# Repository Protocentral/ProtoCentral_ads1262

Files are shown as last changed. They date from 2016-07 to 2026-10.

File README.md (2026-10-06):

ADS1262 Breakout Board
=======================

ADS1262 32-bit, 11-Channel Multifunction Low-Noise, High-Resolution ADC Breakout Board (PC-4143)

[Don't have it yet? Buy one here: ProtoCentral ADS1262 32-bit precision ADC breakout board (PC-4143)](https://protocentral.com/product/protocentral-ads1262-32-bit-precision-adc-breakout-board/)
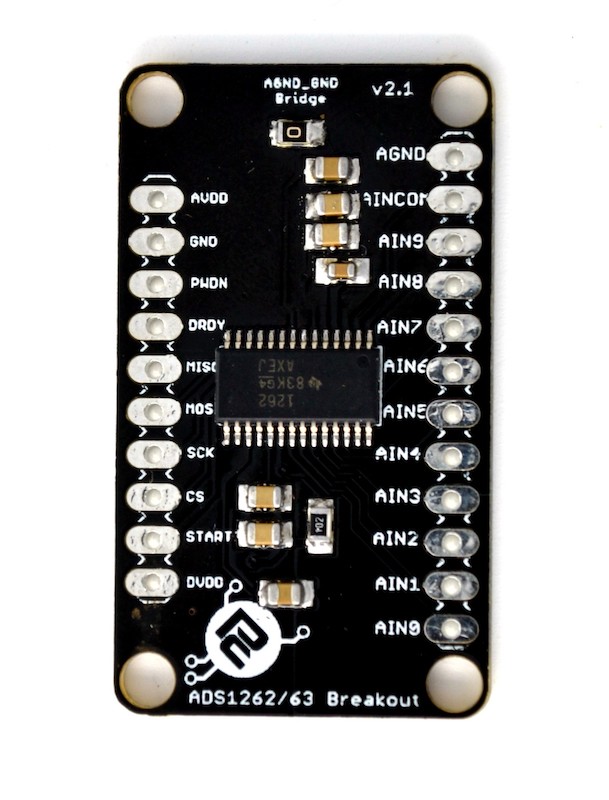
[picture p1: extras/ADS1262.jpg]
ADC breakout


The 24-bit ADS1220 ADC still not enough for you? Need more? Look no further than the ADS1262 from Texas Instruments — a 32-bit Delta-Sigma ADC with a built-in PGA, voltage reference, current sources and everything else but the kitchen sink.

What does 32-bit precision mean to you? Compared to a commonly used 12-bit ADC which can provide 4,096 levels of the input analog voltage, a 32-bit ADC can, in theory, provide 4,294,967,296 levels!

Now plug-in your high-precision strain gauge or load cell directly to this ADC without any external analog signal conditioning. Whether it is for ultra-high precision weighing scales, strain gauges, RTDs or chemical sensors, you can be assured that you will get the highest available precision from this breakout board.

Features
---------
* Ultra-high precision 32-bit Delta-Sigma ADC
* 11 programmable analog inputs (AIN0-AIN9 + AINCOM)
* Differential Input Programmable Gain Amplifier (PGA): 1x to 32x
* Programmable Data Rates: 2.5 SPS to 38.4 kSPS
* 2 built-in current sources for sensor excitation
* Built-in programmable digital filter
* Internal Voltage Reference (2.5 V)
* Internal temperature sensor
* SPI interface
* 3.3V or 5V operation

Specifications
---------------

### Input Ranges (with 2.5V internal reference)

| Gain | Input Range  | Optimal Use Case |
|:----:|:---:|---|
| 1x | +/-2.5V | High voltage signals |
| 2x | +/-1.25V | Medium voltage signals |
| 4x | +/-625mV | Low voltage signals |
| 8x | +/-312.5mV | Very low voltage signals |
| 16x  | +/-156.25mV  | Strain gauges |
| 32x  | +/-78.125mV  | Ultra-low signals, load cells |

Applications
-------------
* High precision analog voltage measurement
* Strain gauges and load cells
* RTD (Resistance Temperature Detector) interfacing
* Thermocouple measurement
* High precision chemical sensors (pH, conductivity)
* Multi-channel data acquisition systems
* Calibration and reference equipment

Wiring to your Arduino
-----------------------
| ADS1262 Pin | Pin Function | Arduino Connection |
|---|:---:|---:|
| DRDY | Data Ready Output | D6 |
| MISO | Slave Out (SPI) | D12 |
| MOSI | Slave In (SPI) | D11 |
| SCLK | Serial Clock (SPI) | D13 |
| CS | Chip Select | D7 |
| START | Start Conversion | D5 |
| PWDN | Power Down / Reset | D4 |
| DVDD | Digital VDD | +5V |
| DGND | Digital Gnd | GND |
| AN0-AN9 | Analog Inputs | Analog Input |
| AINCOM | Analog Input Common  | |
| AVDD | Analog VDD | +5V |
| AGND | Analog Gnd | GND |

Getting Started
----------------

Install the library through the Arduino Library Manager (search for "ProtoCentral ADS1262") or clone this repository into your Arduino libraries folder.

```cpp
#include <ads1262.h>

ADS1262 adc;

void setup() {
    Serial.begin(115200);

    if (!adc.begin()) {
        Serial.println("Failed to initialize ADS1262!");
        while(1);
    }

    // Configure for your application
    adc.setDataRate(ADS1262_DR_100_SPS);
    adc.setGain(ADS1262_GAIN_1);
    adc.setInputMux(ADS1262_AIN0, ADS1262_AIN1);
}

void loop() {
    float voltage = adc.readVoltage();
    Serial.print("Voltage: ");
    Serial.print(voltage, 6);
    Serial.println(" V");
    delay(1000);
}
```

The example sketches are configured for internal Vref = 2.50V and differential voltage measurement across AIN0 and AIN1.

Repository Contents
-------------------
* **/src** - Arduino library source files
* **/examples** - Example Arduino sketches
* **/Hardware** - Eagle design files (.brd, .sch) for the original board
* **/Hardware/v4** - KiCad design files and schematic PDF for the v4 board (single 3.3 V / 5 V supply pin, on-board LM2775 charge pump)
* **/extras** - Includes the datasheet

License Information
===================

License

This product is open source! Both, our hardware and software are open source and licensed under the following licenses:

Hardware
---------

**All hardware is released under the [CERN-OHL-P v2](https://ohwr.org/cern_ohl_p_v2.txt)** license.

Copyright CERN 2020.

This source describes Open Hardware and is licensed under the CERN-OHL-P v2.

You may redistribute and modify this documentation and make products
using it under the terms of the CERN-OHL-P v2 (https:/cern.ch/cern-ohl).
This documentation is distributed WITHOUT ANY EXPRESS OR IMPLIED
WARRANTY, INCLUDING OF MERCHANTABILITY, SATISFACTORY QUALITY
AND FITNESS FOR A PARTICULAR PURPOSE. Please see the CERN-OHL-P v2
for applicable conditions

Software
--------

**All software is released under the MIT License(http://opensource.org/licenses/MIT).**

THE SOFTWARE IS PROVIDED "AS IS", WITHOUT WARRANTY OF ANY KIND, EXPRESS OR IMPLIED, INCLUDING BUT NOT LIMITED TO THE WARRANTIES OF MERCHANTABILITY, FITNESS FOR A PARTICULAR PURPOSE AND NONINFRINGEMENT. IN NO EVENT SHALL THE AUTHORS OR COPYRIGHT HOLDERS BE LIABLE FOR ANY CLAIM, DAMAGES OR OTHER LIABILITY, WHETHER IN AN ACTION OF CONTRACT, TORT OR OTHERWISE, ARISING FROM, OUT OF OR IN CONNECTION WITH THE SOFTWARE OR THE USE OR OTHER DEALINGS IN THE SOFTWARE.

Documentation
-------------
**All documentation is released under [Creative Commons Share-alike 4.0 International](http://creativecommons.org/licenses/by-sa/4.0/).**


You are free to:

* Share — copy and redistribute the material in any medium or format
* Adapt — remix, transform, and build upon the material for any purpose, even commercially.
The licensor cannot revoke these freedoms as long as you follow the license terms.

Under the following terms:

* Attribution — You must give appropriate credit, provide a link to the license, and indicate if changes were made. You may do so in any reasonable manner, but not in any way that suggests the licensor endorses you or your use.
* ShareAlike — If you remix, transform, or build upon the material, you must distribute your contributions under the same license as the original.

Please check [*LICENSE.md*](LICENSE.md) for detailed license descriptions.

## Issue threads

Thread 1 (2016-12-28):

Specified folder/zip file does not contain a valid library

ecaits, 2016-12-28:
I have installed this library but when I compile the example code I got the error of Specified folder/zip file does not contain a valid library.

What can be the issue???

VenkateshBhat, 2016-12-28:
Please unzip the files, and place the src file in appropriate folder ,in the Arduino IDE, navigate to Sketch > Include Library.

ecaits, 2016-12-28:
Already unzip the files but no src file is found. Can you please suggest for that?
Send me the link for that.

ecaits, 2016-12-28:
Now its working... There was a spelling mistake in example.ino file....
I have used MISO, MOSI, CS, SCK, Start and DRDY pin... I have not used PWDN pin as I have limited pins on boards....
Thanks for your support...

aravindaguru, 2018-02-16:
I have installed this library but when I compile the example code I got the error of Specified folder/zip file does not contain a valid library.i have unzip the files but no src file is found. Can you please suggest for that?

aravindaguru, 2018-02-16:
i am getting this error
 C:\Users\manoj12126\AppData\Local\Temp\Temp1_ProtoCentral_ads1262-master.zip\ProtoCentral_ads1262-master\Libraries\example\example.ino:24:28: fatal error: SoftwareSerial.h: No such file or directory  #include <SoftwareSerial.h>

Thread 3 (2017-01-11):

ADS1262 and 2.2 SPI TFT (Two SPI Slave) with Arduino

ecaits, 2017-01-11:
Hello,

I am interfacing two SPI slave module i.e. ADS1262 and 2.2 SPI TFT with Arduino Ethernet board.
Now in SPI, at a time one device can access. Initially, I have interfaced TFT and it is working fine.
Then I have interface ADS1262 and trying to access after TFT through program code but it is not accessible.
Whereas the example code of ADS1262 is working fine when I am running it alone.
After adding the example code in TFT’s code (and communicating after tft) but it is not working.

I think it may the issue of ADS1262_CS or ADS1262_START or ADS1262_DRDY pin sequence to access the ADS1262.
I have used this library, https://github.com/Protocentral/ProtoCentral_ads1262/tree/master/Libraries and example of it.

Can you suggest for above issue.

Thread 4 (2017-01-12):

Single-Ended mode

Sumsa, 2017-01-12:
Hi There,

Do you have any idea how to make this work in Single-Ended mode? i.e measure the voltage difference between input A0 and COM. The documentations says the 1262 should be able to operate in this mode, but I cant figure out how to switch when looking at the example.

Along the same lines, where do I make changes if i want to measure from different pins than AN0 And AN1?

ecaits, 2017-01-13:
You need use INPMUX register to set the different analog pin as input.

Sumsa, 2017-01-17:
Thank you for pointing me in the right direction. Here is a small guide for people having the same problem.

for single mode operation connect the negative differential pin to ground using a jumper wire.

Change the pins used in line 78 in ads1262.cpp

e.g change the hex value next to INPMUX to a binary number as stated on page 94 in the datasheet. eg
ads1262_Reg_Write(INPMUX, B00000001); // will be AIN pin 0 and 1
ads1262_Reg_Write(INPMUX, B01110010); // will be AIN pin 7 and 2

To change the sampling rate to 10Hz where there is the highest db 50/60Hz noise reduction change mode 2 at line 62 to:
ads1262_Reg_Write(MODE2, B00000010);

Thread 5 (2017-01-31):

ADS1262 activation issue

ecaits, 2017-01-31:
I am interfacing ADS1262 with Arduino mega2560 along with TFT, sd card and AD420.
The example given in library of ads1262 is working perfectly but when I interface ads1262 with other slave at that time, sometimes it activate and given output and sometimes it does not activate so not getting serial output.

Is there voltage related problem or anything else?

VenkateshBhat, 2017-02-01:
Hi ecaits,

Sorry for the inconvenience caused, could you please share your design? What other slave you are interfacing with?

ecaits, 2017-02-06:
I am interfacing TFT 2.2 SPI and SD Card along with ProtoCentral_ads1262 ADS1262.
When I run the code, the ADS1262 gives wrong value. Although it is giving perfect value when running independently.
What may be the issue. I have attached photo of interfacing design.
[Circuit.pdf](https://github.com/Protocentral/ProtoCentral_ads1262/files/754511/Circuit.pdf)

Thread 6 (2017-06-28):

PDF of v3 Schematics / Layout

josschne, 2017-06-28:
Could we get a PDF of the v3 hardware schematics and layout for those without Eagle?

I see the v3 design files but no PDF.
https://github.com/Protocentral/ADS1292rShield_Breakout/tree/master/Hardware/ECG_BOB

VenkateshBhat, 2017-06-29:
Thank you for bringing this to our attention, now we have added the pdf file for the breakout https://github.com/Protocentral/ADS1292rShield_Breakout/tree/master/Hardware/ECG_BOB

josschne, 2017-06-29:
Thanks for the fast response. However, the PDF is missing the second sheet.

Could I see the second sheet too? The v3 hardware has logic level selection circuitry that I'd like to examine.

VenkateshBhat, 2017-06-30:
added, do check.

josschne, 2017-06-30:
Thanks!

Closed 2017-06-29.

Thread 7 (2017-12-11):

VDD

eduhza, 2017-12-11:
Hi,

I want to sugest that next version of "PROTOCENTRAL ADS1262 32-BIT PRECISION ADC BREAKOUT BOARD" have an option to use as VDD +5V or +3.3V so we can use with newest hardwares such as ESP8266, arduino 3.3V or Adafruit Feather etc.

VenkateshBhat, 2017-12-11:
@eduhza Noted, thanks for your comment.
We have these options in our latest version and we are updating the Board images, hardware design files soon.

eduhza, 2018-02-28:
@VenkateshBhat how about the new hardware design? I need the .brd file to get sizes for prototyping.

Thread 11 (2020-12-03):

Request for help: Changing to hgiher sample rate and turning off filtering

JamesTimothyMeech, 2020-12-03:
Hello, thanks for all the great work on the breakout board and the accompanying code.

I'm attempting to up the sample rate to 38400 SPS.

To do this I have changed the values written to the MODE1 and MODE2 registers as follows:

  ads1262_Reg_Write(MODE1, 0x60);
  delay(10);
  ads1262_Reg_Write(MODE2, 0x0F);

When I run the code with these values I observe rail to rail random variation in the output in the signal even when measuring a constant voltage. This is not the expected operation.

Am I missing some other register value that I need to change to get this to work?

HSMinches, 2020-12-03:
Hello James! Did u setup your INPMUX registers instead of just setting up the MODES?  e.g. :

PC_ADS1262.ads1262_Reg_Write(INPMUX, B00001010); // ain0 - aincom
PC_ADS1262.ads1262_Reg_Write(MODE1, B01100000);
PC_ADS1262.ads1262_Reg_Write(MODE2, B01010000);

And regarding the Voltage supply of the ADC are u using +- 2.5V or  +5V? I am asking because this will interfere depending on the measurement mode you are using ( PGA enabled or disabled, and the negative measure reference as well). I suggest that you take a look at page 119 of the ads1262 datasheet for more info on that matter.

Best regards.
Heitor S. Mendes

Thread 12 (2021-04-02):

Trying to connect to portenta H7 without any success

christosnc, 2021-04-02:
Hello 👋,

I am using an Arduino Portenta H7, and an analog light sensor. I tested the sensor with the on-board ADC of the arduino and I can read the values (so the sensor works).

This is the pinout for the Portenta:
https://content.arduino.cc/assets/Pinout-PortentaH7_latest.png

The connections I'm using are as follows:
```
AVDD             -> 5V (top right pin)
GND              -> GND
PWDN             -> D20
DRDY             -> D21
MISO             -> D10
MOSI             -> D8
SCK              -> D9
CS               -> D7
START            -> D4
DVDD             -> 5V (top right pin)

AGND             -> GND
AIN0             -> Analog output of the sensor
AIN1             -> GND
```

I also changed the pin constants in **ads1262.h** as follows:
```
const int ADS1262_DRDY_PIN = 21;
const int ADS1262_CS_PIN = 7;
const int ADS1262_START_PIN = 4;
const int ADS1262_PWDN_PIN = 20;
````

Finally, in **ads1262.cpp** I removed the deprecated SPI calls (setBitOrder, setDataMode, setClockDivider) and before every `SPI.transfer()` call, I added `SPI.beginTransaction(SPISettings(1000000, MSBFIRST, SPI_MODE1));` and after each transfer I added `SPI.endTransaction();`

#

The only thing I'm getting is "ads1262 Initialised successfully...." and that's it. I wasn't able to get a single reading, no matter what arrangement I tried.

Please help!

christosnc, 2021-04-02:
Update:

I changed the DDRY and PWDN pins to D3 and D2 accordingly and now I started getting readings.
There must be an issue with pins that can be used as analog, IDK.

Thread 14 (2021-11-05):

ADS1262 - Unable to acquire data

NikGreek, 2021-11-05:
Hello, I'm trying to connect the ads1262 with an arduino uno so I can measure voltage with higher precision.
I'm using the same connections you suggest and the same code.
However in serial monitor, I only get the "successful initialization" message and then nothing or I get only zero values of voltage.
I apply the analog signal from a NI ELVIS III breadboard.
Is this something you can help me with ?
Thank you in advance!

LAWBear, 2021-12-17:
I remain hopeful for suggestions/guidance on ADS1262 data values from ProtoCentral ADS1262 "1-Simple_Differential.ino".  Have upgraded MCU from Feather M0 to Feather M4 Express, and **commented** sketch "#include <SoftwareSerial.h> since previous comment.

Data "readout voltage/mv" remains 0.00 & 0.00 resp.

I embed logic analyzer image but cannot include *.rar archive of Saleae logic files for analysis.  Data only displays intermittently or at interval(s) of ~732ms??

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

Analyzer traces self labeled and arranged for clarity of response and issue.

PLEASE advise steps for further testing or diagnositcs.

LAWBear, 2022-02-07:
> Hello, I'm trying to connect the ads1262 with an arduino uno so I can measure voltage with higher precision. I'm using the same connections you suggest and the same code. However in serial monitor, I only get the "successful initialization" message and then nothing or I get only zero values of voltage. I apply the analog signal from a NI ELVIS III breadboard. Is this something you can help me with ? Thank you in advance!

LAWBear, 2022-02-07:
I MAY be getting close to successful configuration of the ADS1262 and the Feather M4 Express as an SD card data acquisition system.  This configuration also provides GPS header statements in each file, and fairly large SD cards (32Gb & 64Gb) using Fat32 or ExFat with 32k clusters and 128k clusters resp.  I am storing raw binary at up to 38.4 ksps to the SD card with some reasonable success, but still struggling a bit to get the ADS1262 to "start" and/or "sync" with the sample clocks.  To the interests of wizards I include my crude sketch.  Further, to some other inquiries, I have also successfully "tested" the ProtoCentral on Arduino Uno R3. and the "example" sketch.  (currently using pushbutton(s) to start file for selected DURATION)

Comments/Guidance appreciated:

``/*Compiled for Feather M4 Express (SAMD51)
Sample rate and ADS1262 tuning done in modified ads1262.cpp
Using data buffer sized for 32Gb Sandisk Extreme SD card
Sketch includes some place-holders for AirLift ESP32 Coprocessor (future work)*/

#include <SPI.h>
#include <SdFat.h>
#include <stdint.h>
#include <Adafruit_GPS.h>
#include <ads1262.h>
//#include <WiFiNINA.h>
#include <stdio.h>

#define SPI_SPEED SD_SCK_MHZ(12)
#define DURATION 10               // RECORDING DURATION
int count1=0;
SdFat SD;
File myFile;
char filename[15];

// name of the GPS hardware serial port?
#define GPSSerial Serial1

// Connect to the GPS on the hardware port
Adafruit_GPS GPS(&GPSSerial);

String NMEA1;
String NMEA2;
char c;

//AirLIft WiFi
const int WIFININA_SLAVESELECT = 13;
const int WIFININA_SLAVERESET = 12;
const int WIFININA_SLAVEREADY = 11;

const int ledStart = A1;
const int ledStop = A2;
const int btnStart = A3;
const int btnStop = A4;
unsigned long startRecTime = 0;
const int sd_cs_pin = 10;  //Feather M4 SD card chip-select pin
//const int GPO = ??       //not available until pushbuttons & LED's released for external controls

//Pins used for the connection with the sensor, the others are controlled by the SPI library):  (Feather M4 pins assigned in ads1262.h)
//const int ADS1262_DRDY_PIN = 6;
//const int ADS1262_CS_PIN = 9;
//const int ADS1262_START_PIN = 5;
//const int ADS1262_PWDN_PIN = A0;

int recPressed = 0;
int stopPressed = 0;
int flag = 0;

ads1262 PC_ADS1262;  //ADS class

//ADS1262 global
#define PGA 1                     // Programmable Gain = 1
#define VREF 2.50                 // Internal reference of 2.048Vc
#define VFSR VREF/PGA     
#define FSR (((long int)1<<23)-1)

#define START1 0x08
#define STOP1 0x0A
#define RDATA1 0x12

//float volt_V=0;
//float volt_mV=0;
volatile int i;
volatile char SPI_RX_Buff[10];
volatile long ads1262_rx_Data[10];
volatile static int SPI_RX_Buff_Count = 0;
volatile char *SPI_RX_Buff_Ptr;
volatile int Responsebyte = false;

unsigned char  buffer1[32000];
int newData = 0; // new data from adc?
int index1=0;

void setup()
{
  // 9600 baud is the default rate for the Ultimate GPS/Featherwing
  GPSSerial.begin(9600);

  GPS.sendCommand(PMTK_SET_NMEA_OUTPUT_RMCGGA);
  // Default is 1 Hz update rate
  GPS.sendCommand(PMTK_SET_NMEA_UPDATE_1HZ);
  delay(1000); //Pause

  pinMode(WIFININA_SLAVESELECT,OUTPUT);     //AirLift_WiFi_CS_PIN 13
  pinMode(WIFININA_SLAVERESET,OUTPUT);      //AirLift_WiFi_RST_PIN 12
  pinMode(WIFININA_SLAVEREADY ,INPUT);      //AirLift_WiFi_DRDY_PIN 11

  pinMode(10, OUTPUT);                      // DON'T change this(10) - Hardware sd_cs_pin pin must be left as output for SD library functions to work correctly
  pinMode(ledStart, OUTPUT);                //A1 pushbutton,to be replaced with BLE replies later
  pinMode(ledStop, OUTPUT);                 //A2 pushbutton,to be replaced with BLE replies later
  pinMode(btnStart, INPUT_PULLUP);          //A3 Blue LED,to be replaced with BLE commands later
  pinMode(btnStop, INPUT_PULLUP);           //A4 Green LED,to be replaced with BLE commands later
  pinMode(sd_cs_pin, OUTPUT);               //10 SD enable (Feather M4 Express)
//  pinMode(GPO,OUTPUT);                    //?? Used in BLE mode, not available until pushbuttons & LED's released for external controls

  // initalize the  data ready and chip select pins:
  pinMode(ADS1262_DRDY_PIN, INPUT);         //data ready input line (Feather M4- pin 6)
  pinMode(ADS1262_CS_PIN, OUTPUT);          //chip enable output line (Feather M4- pin 9)
  pinMode(ADS1262_START_PIN, OUTPUT);       // start (Feather M4- pin 5)
  pinMode(ADS1262_PWDN_PIN, OUTPUT);        // Power down output (Feather M4- pin A0)

  digitalWrite(WIFININA_SLAVESELECT, HIGH);

  Serial.begin(115200);       // Max Baud Rate
  SD.begin();                 //Start SD card library
//  SPI.begin();           // start SPI library
  SPI.beginTransaction(SPISettings(SPI_SPEED, MSBFIRST, SPI_MODE1));

  digitalWrite(ADS1262_PWDN_PIN,HIGH);
  digitalWrite(ADS1262_PWDN_PIN,LOW);
  digitalWrite(ADS1262_PWDN_PIN,HIGH);    // hold high for operating
  delay(10);

  digitalWrite(10, HIGH);

    if (SD.begin(sd_cs_pin,SPI_SPEED)) {        //testing changes to SPI speed
    delay(10);

  for (int dloop = 0; dloop < 4; dloop++) {
        digitalWrite(ledStart,!digitalRead(ledStart));
        delay(100);
      }
    }
    else { // if error, flash LED twice per second, until reset
      while(1) {
        digitalWrite(ledStart,!digitalRead(ledStart));
        delay(500);
      }
    }
  strcpy(filename, "ANALOG00.BIN");   // Template for file name, characters 6 & 7 get set automatically later
  SD.ls(LS_R | LS_DATE | LS_SIZE);  // list the files

    PC_ADS1262.ads1262_Init(); //initialize ads126
    delay(10);

//    PC_ADS1262.ads1262_SPI_Command_Data(START1);
//    delay(10);

 }

void loop()
{
  if (digitalRead(btnStart) == LOW && recPressed == 0) {
    StartRec(); // launch StartRec method
    startRecTime = millis();
  }
  if (digitalRead(btnStop) == LOW) {
    StopRec(); // launch StopRec method
  }

  if(recPressed){
    if( (millis() - startRecTime)  > 1000)
    {
      count1++;
      if(count1 >= DURATION)
      {
      StopRec();
      count1 =0;
      }
      startRecTime = millis();
    }
  }

    if((digitalRead(ADS1262_DRDY_PIN)) == LOW)               // monitor Data ready(DRDY pin)
    {
    SPI_RX_Buff_Ptr = PC_ADS1262.ads1262_Read_Data();  //6Bytes <STATUS|DATA1|DATA2|DATA3|DATA4|CHECKSUM>
    Responsebyte = true;
    }
    if(Responsebyte == true)
    {
      for(i = 0; i <5; i++) //Remove STATUS byte?
      {
      SPI_RX_Buff[SPI_RX_Buff_Count++] = *(SPI_RX_Buff_Ptr + i);      
      }
    Responsebyte = false;
    }

  if(SPI_RX_Buff_Count >= 5)
  {
    ads1262_rx_Data[0]= (unsigned char)SPI_RX_Buff[1];  // read 4 bytes adc count
    ads1262_rx_Data[1]= (unsigned char)SPI_RX_Buff[2];
    ads1262_rx_Data[2]= (unsigned char)SPI_RX_Buff[3];
    ads1262_rx_Data[3]= (unsigned char)SPI_RX_Buff[4];

    for(int i = 0; i < 4 ; i++)
    {
      buffer1[index1++] = ads1262_rx_Data[i];
    }

    SPI_RX_Buff_Count = 0;
    if(index1 >= 32000)
    {
      newData =1;
      index1 = 0;
    }
  }

    if(recPressed && (newData == 1) )
    {

    myFile = SD.open(filename, O_RDWR | O_APPEND);  //re-open file to append buffer data in "loop"
    myFile.write(buffer1,32000);

    index1 = 0;
    myFile.close();
    newData = 0;
    }
 }

void StartRec()   // start recording method
{
    digitalWrite(ledStart,HIGH);
    digitalWrite(ledStop,LOW);

    recPressed = 1;
    stopPressed = 0;

    for (uint8_t i = 0; i < 100; i++) {
    filename[6] = '0' + i/10;
    filename[7] = '0' + i%10;
    //create if does not exist, do not open existing, write, sync after write
    if (! SD.exists(filename)) {
      break;
    }
  }
  readGPS();  //This is a function below which reads two NMEA sentences from GPS to create record "header"

  myFile = SD.open(filename, FILE_WRITE);

//  Serial.println(NMEA1);  //Uncomment these lines to display GPGGA on serial monitor,       !!! Start loop will not execute if serial monitor is not displayed
//  delay(10);
//  Serial.println(NMEA2);  //Uncomment these lines to display GPRMC on serial monitor,       !!! Start loop will not execute if serial monitor is not displayed
//  delay(10);

    myFile.println(NMEA1); //try to write NMEA1 GGA as file header
    myFile.close();
    delay(10);
    myFile = SD.open(filename, O_RDWR | O_APPEND);  //re-open file to append NMEA2
    myFile.println(NMEA2); //try to write NMEA2 RMC as file header
    myFile.sync();
    delay(10);

    PC_ADS1262.ads1262_SPI_Command_Data(START1);
    delay(1);
}

void StopRec() { // stop recording method

    digitalWrite(ledStart,LOW);
    digitalWrite(ledStop,HIGH);

    myFile.close();
    recPressed = 0;
}

void readGPS(){  //This function will read and remember two NMEA sentences from GPS
  clearGPS();    //Serial port probably has old or corrupt data, so begin by clearing it all out
  while(!GPS.newNMEAreceived()) { //Keep reading characters in this loop until a good NMEA sentence is received
  c=GPS.read(); //read a character from the GPS
  }
GPS.parse(GPS.lastNMEA());  //Once good NMEA, parse it
NMEA1=GPS.lastNMEA();      //Once parsed, save NMEA sentence into NMEA1

while(!GPS.newNMEAreceived()) {  //Go out and get the second NMEA sentence, should be different type than the first one read above.
  c=GPS.read();
  }
GPS.parse(GPS.lastNMEA());
NMEA2=GPS.lastNMEA();
}

void clearGPS() {  //Since between GPS reads, we still have data streaming in, we need to clear the old data by reading a few sentences, and discarding these
while(!GPS.newNMEAreceived()) {
  c=GPS.read();
  }
GPS.parse(GPS.lastNMEA());
while(!GPS.newNMEAreceived()) {
  c=GPS.read();
  }
GPS.parse(GPS.lastNMEA());
}
''
.

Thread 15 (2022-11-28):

updated schematic and board file ?

icq4ever, 2022-11-28:
hello.
I order and working confirmed but I realized that schematic and board file is not matched with physical board one.
for example, there is no DVDD pin on schematic.
can update that one ?!

thanks!

Vimalish, 2022-11-29:
> hello. I order and working confirmed but I realized that schematic and board file is not matched with physical board one. for example, there is no DVDD pin on schematic. can update that one ?!
>
> thanks!

Any other difference?

icq4ever, 2022-11-30:
@Vimalish as far as I notice, that is all.

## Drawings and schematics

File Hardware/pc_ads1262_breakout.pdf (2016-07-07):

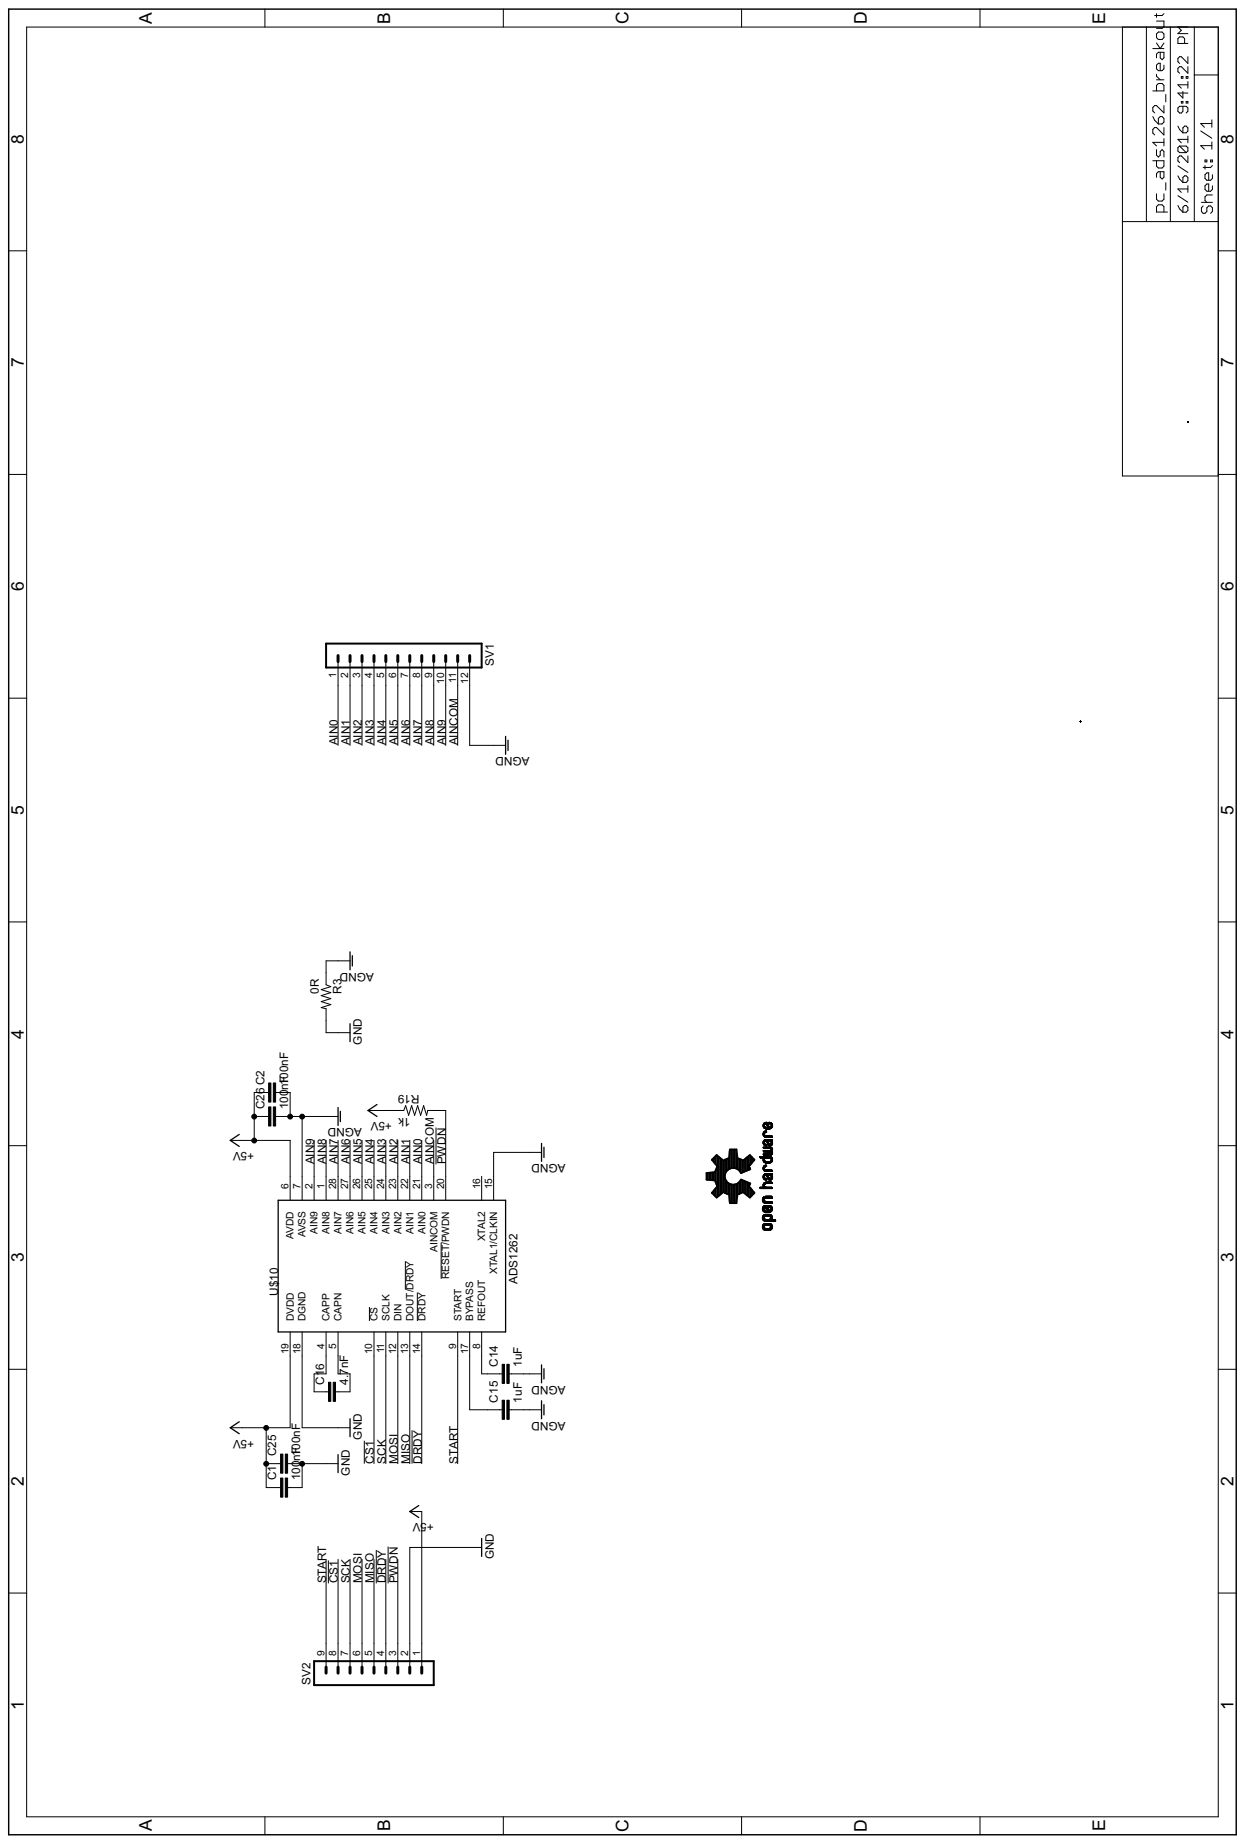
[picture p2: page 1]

ADS1262 GND DNGA 100nF 100nF GND DNGA 1uF 1uF4.7nF k1 V5+ 0R DNGA GND V5+ V5+ DNGA DNGA DNGA 100nF 100nF GND V5+ AIN8 1 AIN9 2 AINCOM 3 CAPP 4 CAPN 5 AVDD 6 AVSS 7 REFOUT 8 START 9 CS 10 SCLK 11 DIN 12 DOUT/DRDY 13 DRDY 14 XTAL1/CLKIN 15 XTAL2 16 BYPASS 17 DGND 18 DVDD 19 RESET/PWDN 20 AIN0 21 AIN1 22 AIN2 23 AIN3 24 AIN4 25 AIN5 26 AIN6 27 AIN7 28 U$10 C25 C26 C14 C1 C5 16 91R R3 SV1 123456789101112 SV2 987654321 C1 C2 SCK SCK MOSI MOSI MISO MISO AIN0 AIN0 AIN1 AIN1 AIN2 AIN2 AIN3 AIN3 DRDY DRDY AINCOM AINCOM PWDN PWDN CS1 CS1 AIN4 AIN4 AIN5 AIN5 AIN6 AIN6 AIN7 AIN7 AIN8 AIN8 AIN9 AIN9 START START ABCDE 1 2 3 4 5 6 7 8 ABCDE 1 2 3 4 5 6 7 8

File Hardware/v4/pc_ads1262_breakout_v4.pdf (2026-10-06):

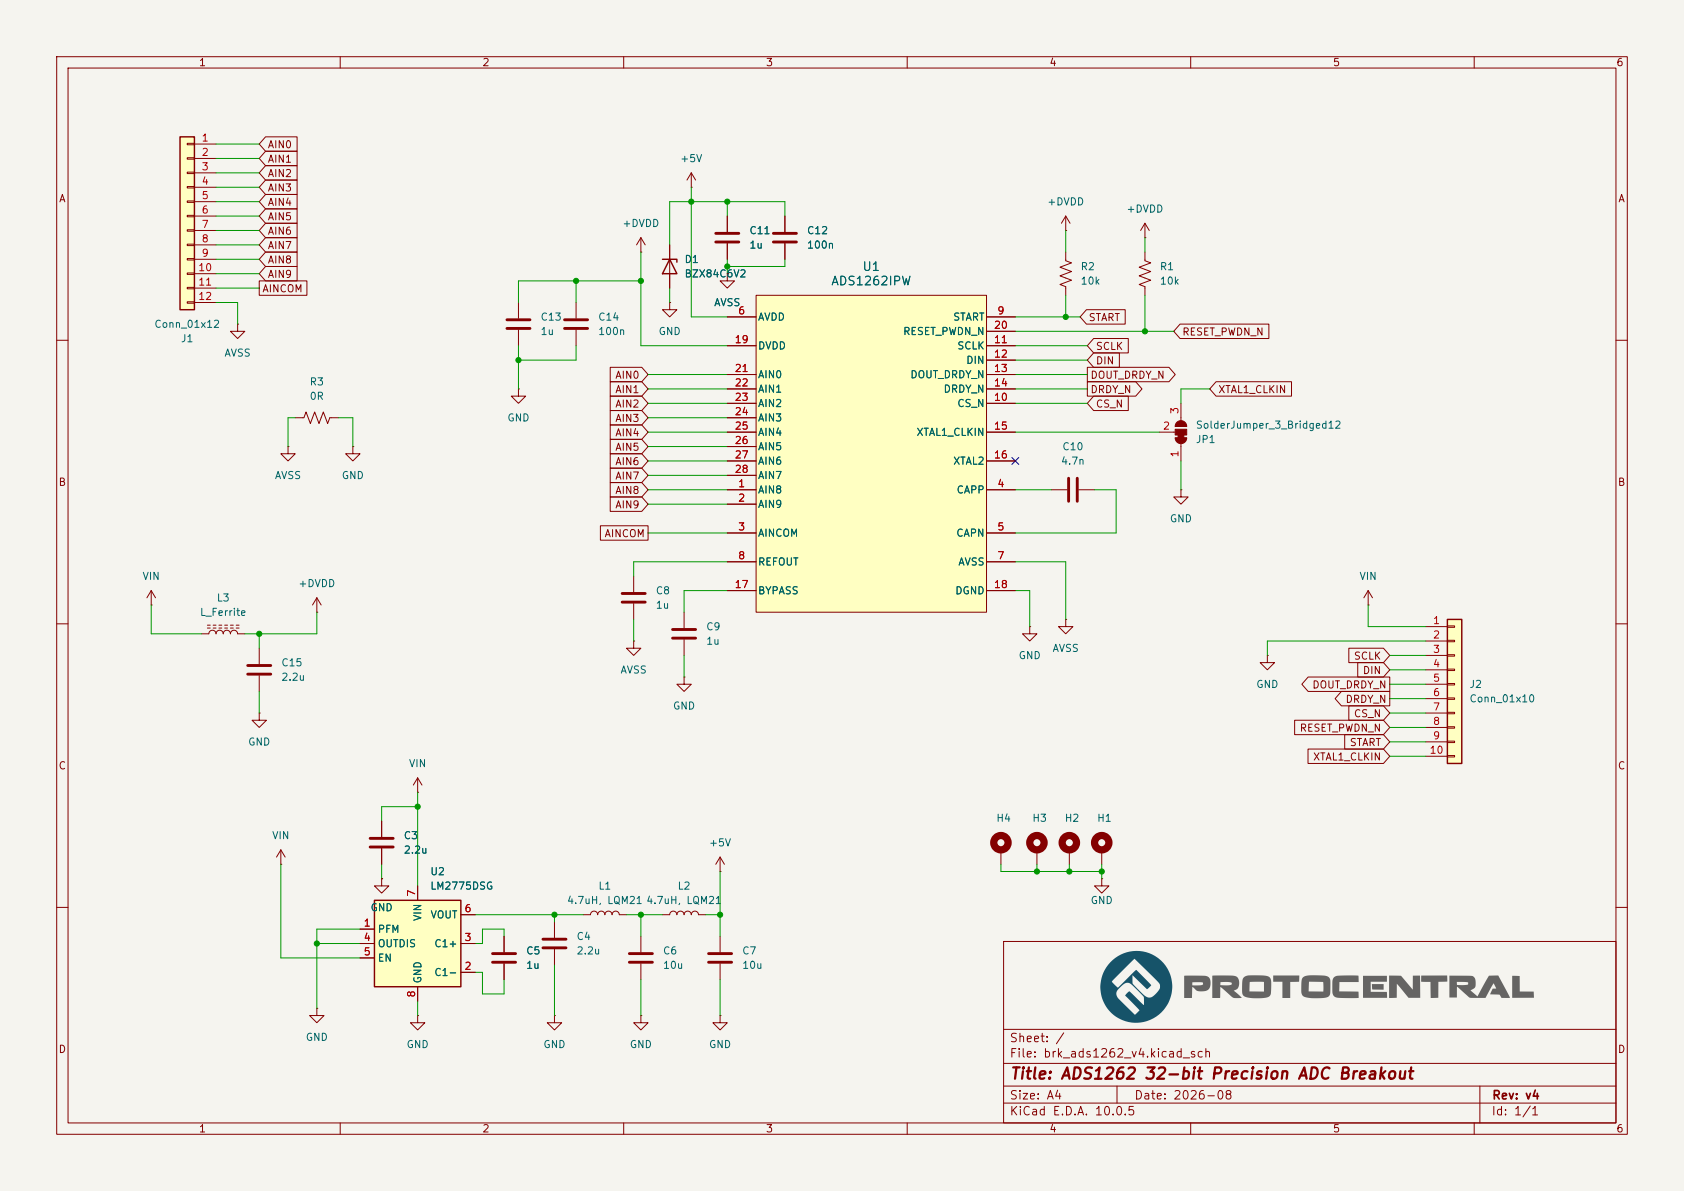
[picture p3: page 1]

Sheet: /
File: brk_ads1262_v4.kicad_sch
Title: ADS1262 32-bit Precision ADC Breakout

Size: A4 | Rev: v4
KiCad E.D.A. 10.0.5 | Id: 1/1

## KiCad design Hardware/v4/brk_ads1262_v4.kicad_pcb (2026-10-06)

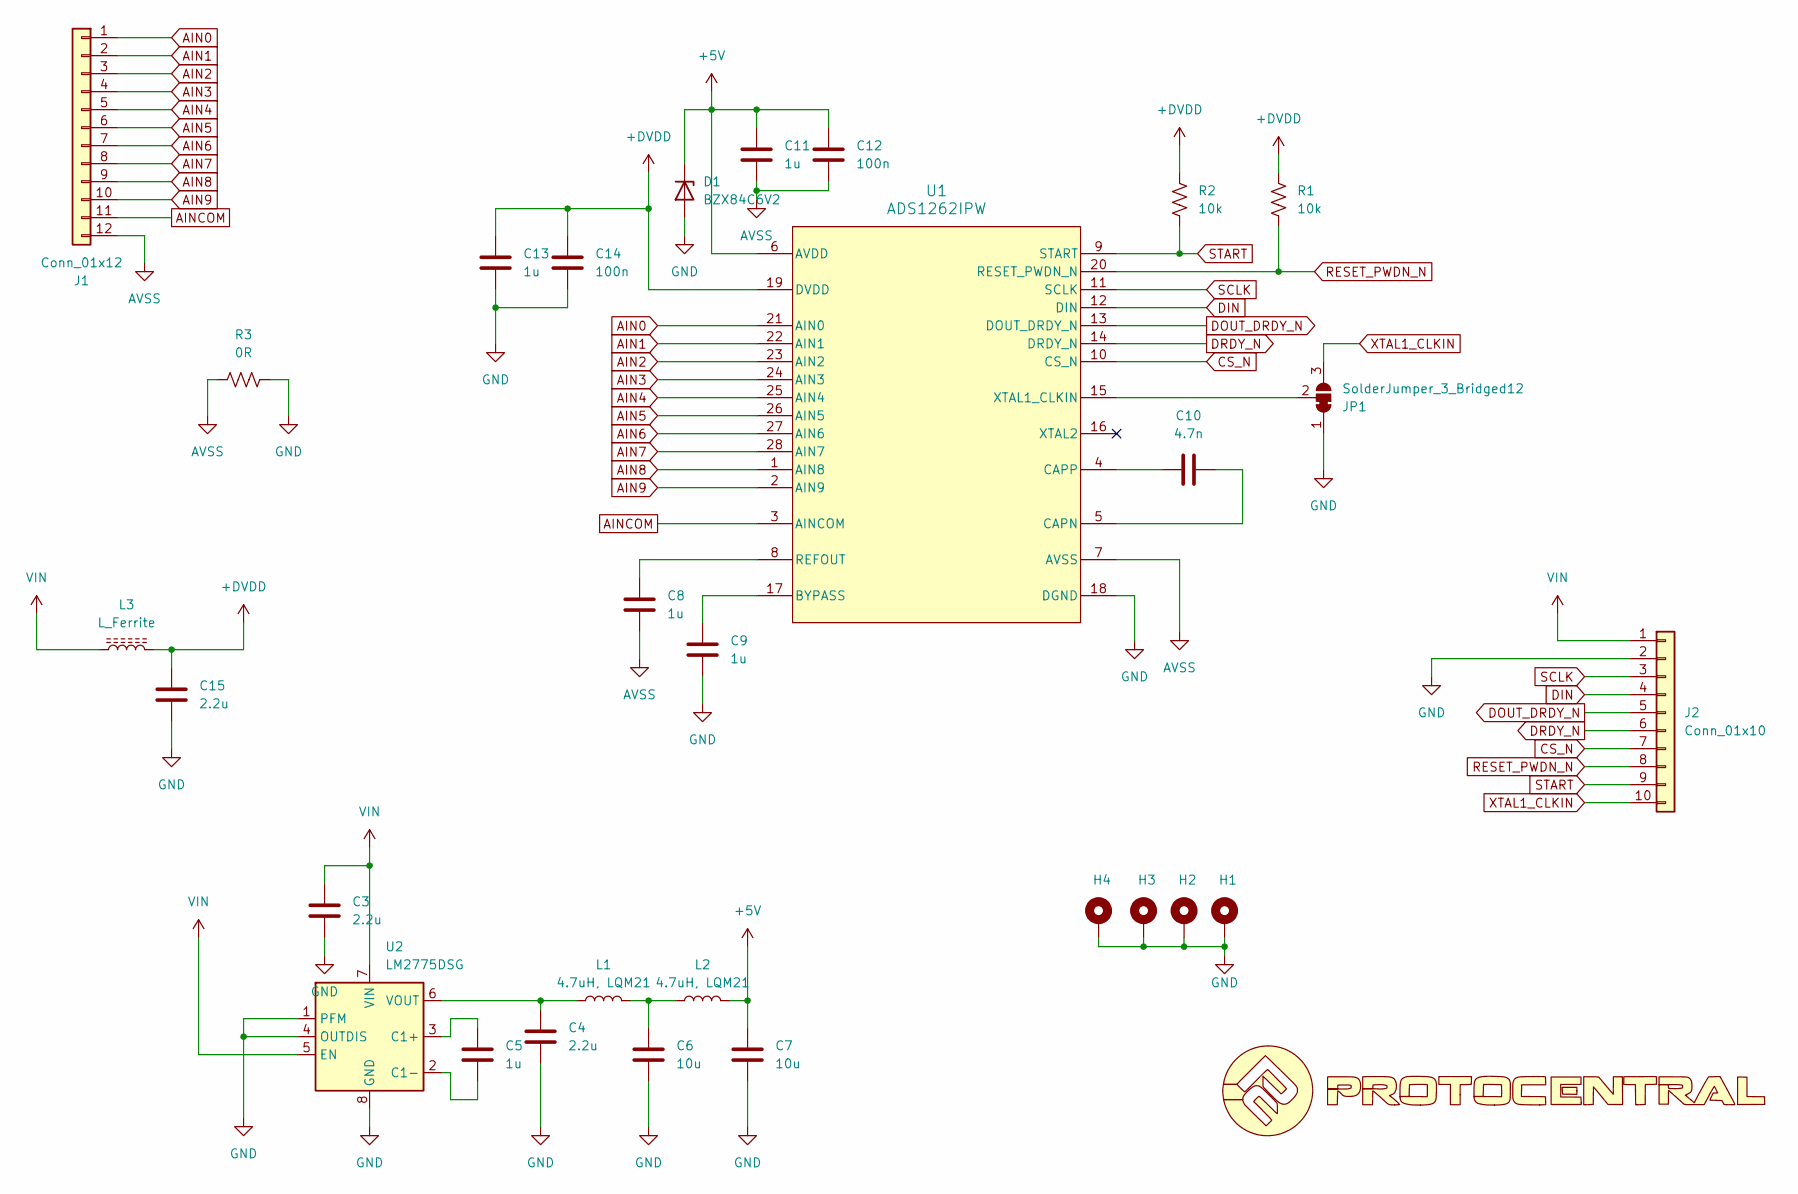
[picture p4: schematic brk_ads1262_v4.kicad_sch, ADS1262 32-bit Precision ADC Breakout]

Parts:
C3, C4, C15: 2.2u; C_0402_1005Metric
C5, C8, C9, C11, C13: 1u; C_0402_1005Metric
C6, C7: 10u; C_0402_1005Metric
C10: 4.7n; C_0402_1005Metric
C12, C14: 100n; C_0402_1005Metric
D1: BZX84C6V2; SOT-23
H1, H2, H3, H4: MountingHole_Pad; MountingHole_2.2mm_M2_DIN965_Pad_TopBottom
J1: Conn_01x12; PinHeader_1x12_P2.54mm_Vertical
J2: Conn_01x10; PinHeader_1x10_P2.54mm_Vertical
JP1: SolderJumper_3_Bridged12; SolderJumper-3_P1.3mm_Bridged2Bar12_RoundedPad1.0x1.5mm_Num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
L1, L2: 4.7uH, LQM21; L_0805_2012Metric
L3: L_Ferrite; L_0805_2012Metric
R1, R2: 10k; R_0402_1005Metric
R3: 0R; R_0402_1005Metric
U1: ADS1262IPW; PW0028A_N
U2: LM2775DSG; Texas_DSG0008A_WSON-8-1EP_2x2mm_P0.5mm_EP0.9x1.6mm_ThermalV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

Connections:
+5V: C7.1, C11.2, C12.2, D1.3 (K), L2.2, U1.6 (AVDD)
+DVDD: C13.2, C14.2, C15.1, L3.2, R1.1, R2.1, U1.19 (DVDD)
AIN0: J1.1, U1.21 (AIN0)
AIN1: J1.2, U1.22 (AIN1)
AIN2: J1.3, U1.23 (AIN2)
AIN3: J1.4, U1.24 (AIN3)
AIN4: J1.5, U1.25 (AIN4)
AIN5: J1.6, U1.26 (AIN5)
AIN6: J1.7, U1.27 (AIN6)
AIN7: J1.8, U1.28 (AIN7)
AIN8: J1.9, U1.1 (AIN8)
AIN9: J1.10, U1.2 (AIN9)
AINCOM: J1.11, U1.3 (AINCOM)
AVSS: C8.2, C11.1, C12.1, J1.12, R3.1, U1.7 (AVSS)
CS_N: J2.7, U1.10 (CS_N)
DIN: J2.4, U1.12 (DIN)
DOUT_DRDY_N: J2.5, U1.13 (DOUT_DRDY_N)
DRDY_N: J2.6, U1.14 (DRDY_N)
GND: C3.2, C4.2, C6.2, C7.2, C9.2, C13.1, C14.1, C15.2, D1.1 (A), H1.1 (1_1), H2.1 (1_1), H3.1 (1_1), H4.1 (1_1), J2.2, JP1.1 (A), R3.2, U1.18 (DGND), U2.1 (PFM), U2.4 (OUTDIS), U2.8 (GND), U2.9 (GND)
unnamed: C6.1, L1.2, L2.1
unnamed: JP1.2 (C), U1.15 (XTAL1_CLKIN)
unnamed: C9.1, U1.17 (BYPASS)
unnamed: C10.2, U1.5 (CAPN)
unnamed: C10.1, U1.4 (CAPP)
unnamed: C8.1, U1.8 (REFOUT)
unnamed: C5.1, U2.3 (C1+)
unnamed: C5.2, U2.2 (C1-)
unnamed: C4.1, L1.1, U2.6 (VOUT)
RESET_PWDN_N: J2.8, R1.2, U1.20 (RESET_PWDN_N)
SCLK: J2.3, U1.11 (SCLK)
START: J2.9, R2.2, U1.9 (START)
VIN: C3.1, J2.1, L3.1, U2.5 (EN), U2.7 (VIN)
XTAL1_CLKIN: J2.10, JP1.3 (B)

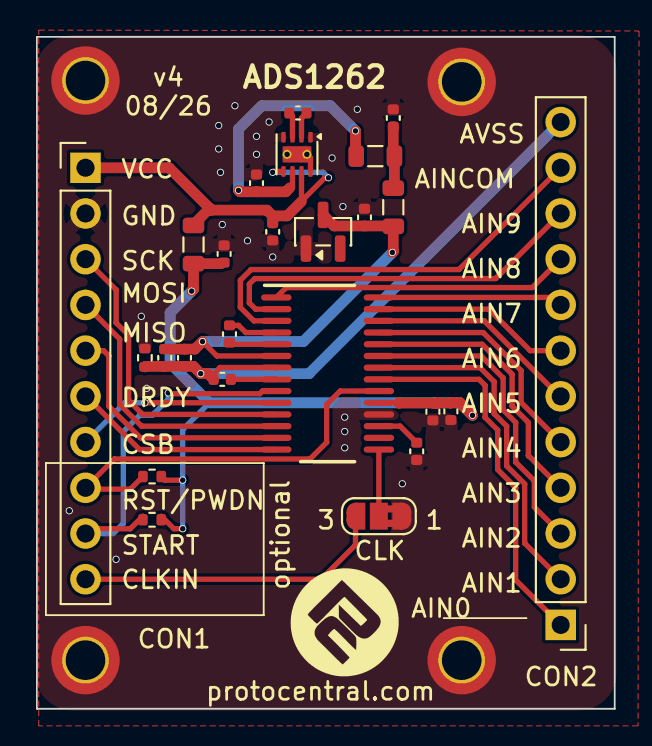
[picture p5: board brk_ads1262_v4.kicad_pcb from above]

Board: 2 copper layers, 32.1 x 37.3 mm, 29 parts (0 on the bottom side), 33 nets.

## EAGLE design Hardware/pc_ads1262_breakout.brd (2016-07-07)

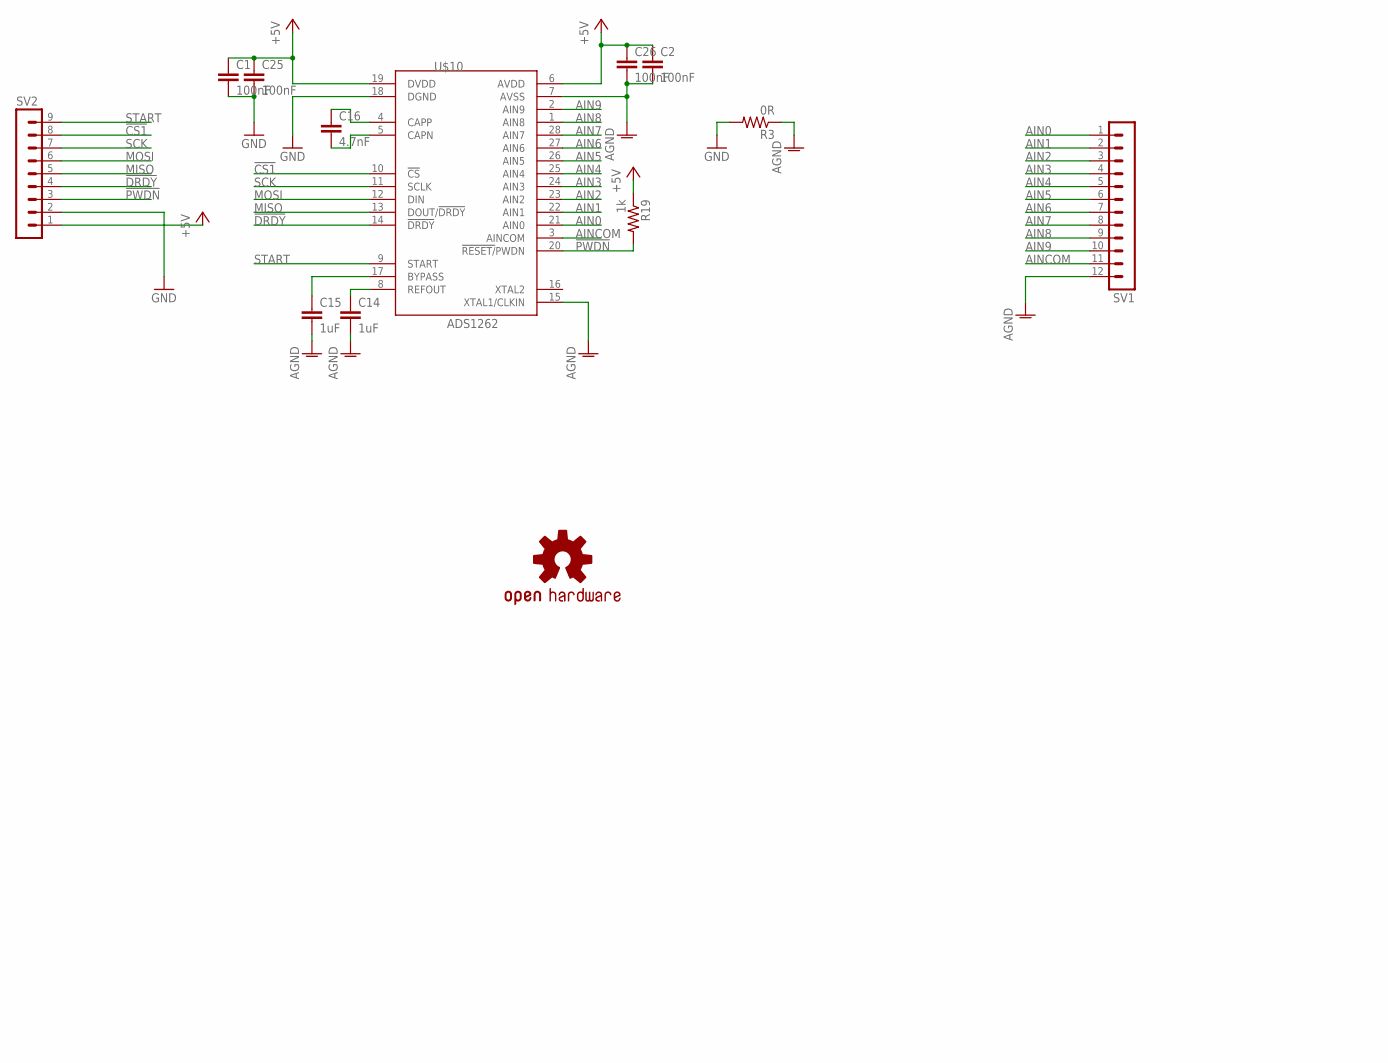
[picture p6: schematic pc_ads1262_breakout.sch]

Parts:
C1, C2, C25, C26: 100nF; C0805
C14, C15: 1uF; C0805
C16: 4.7nF; C0805
R3: 0R; R0805
R19: 1k; R0805
SV1: MA12-1
SV2: MA09-1
U$1: PROTY_LOGO_WITH_TEXT; PROTY_WITH_TEXT
U$2: OSHW-LOGOM; OSHW-LOGO-M
U$3: PROTY-LOGO; LOGO-PROTY
U$10: ADS1262; TSSOP28

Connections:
!CS1: SV2.8, U$10.10 (!CS)
!DRDY: SV2.4, U$10.14 (!DRDY)
!PWDN: R19.2, SV2.3, U$10.20 (!RESET/!PWDN)
+5V: C1.1, C2.1, C25.1, C26.1, R19.1, SV2.1, U$10.6 (AVDD), U$10.19 (DVDD)
AGND: C2.2, C14.2, C15.2, C26.2, R3.1, SV1.12, U$10.7 (AVSS), U$10.15 (XTAL1/CLKIN)
AIN0: SV1.1, U$10.21 (AIN0)
AIN1: SV1.2, U$10.22 (AIN1)
AIN2: SV1.3, U$10.23 (AIN2)
AIN3: SV1.4, U$10.24 (AIN3)
AIN4: SV1.5, U$10.25 (AIN4)
AIN5: SV1.6, U$10.26 (AIN5)
AIN6: SV1.7, U$10.27 (AIN6)
AIN7: SV1.8, U$10.28 (AIN7)
AIN8: SV1.9, U$10.1 (AIN8)
AIN9: SV1.10, U$10.2 (AIN9)
AINCOM: SV1.11, U$10.3 (AINCOM)
GND: C1.2, C25.2, R3.2, SV2.2, U$10.18 (DGND)
MISO: SV2.5, U$10.13 (DOUT/!DRDY)
MOSI: SV2.6, U$10.12 (DIN)
unnamed: C14.1, U$10.8 (REFOUT)
unnamed: C15.1, U$10.17 (BYPASS)
unnamed: C16.1, U$10.4 (CAPP)
unnamed: C16.2, U$10.5 (CAPN)
SCK: SV2.7, U$10.11 (SCLK)
START: SV2.9, U$10.9 (START)

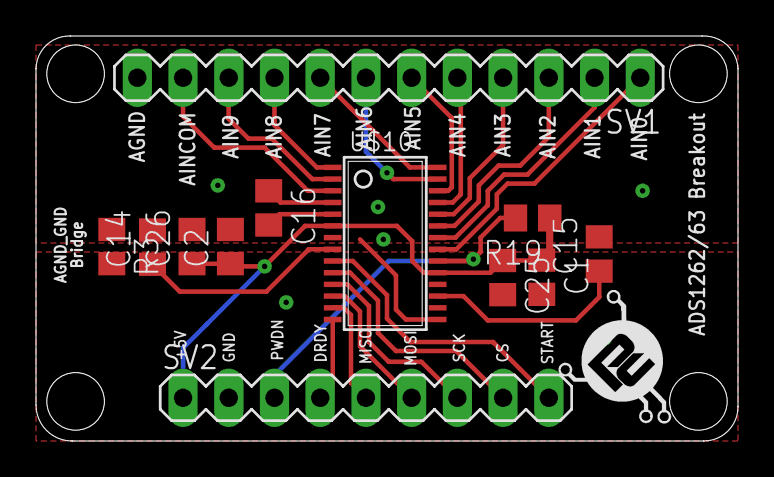
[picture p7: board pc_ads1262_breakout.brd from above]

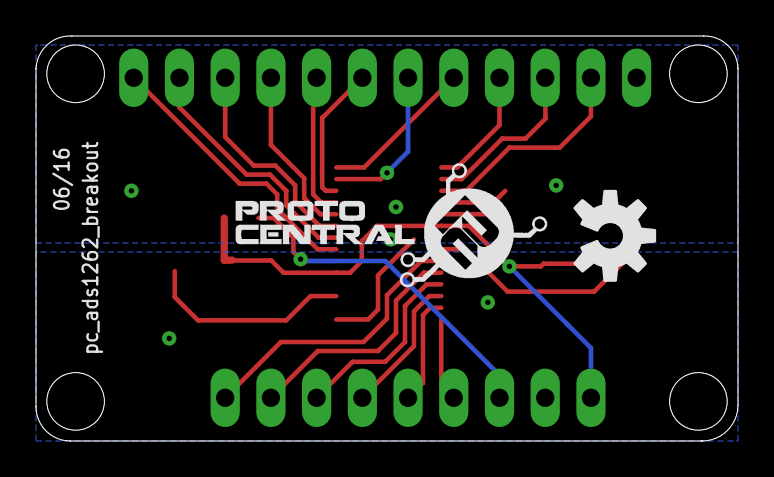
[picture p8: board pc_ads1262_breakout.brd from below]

Board: 4 copper layers, 39.0 x 22.5 mm, 15 parts (2 on the bottom side), 25 nets.

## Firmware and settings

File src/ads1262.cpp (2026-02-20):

/*
 * Arduino library for the ADS1262 32-bit ADC breakout board from ProtoCentral
 * 
 * SPDX-License-Identifier: MIT
 * 
 * Author: Ashwin Whitchurch, Protocentral Electronics
 * Contact: support@protocentral.com
 * Copyright (c) 2020-2025 ProtoCentral Electronics
 *
 * This software is licensed under the MIT License
 * 
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
 * For information on how to use, visit:
 * https://github.com/Protocentral/protocentral-ads1262-arduino
 */

#include "ads1262.h"

// Default constructor - uses default pin assignments and SPI
ADS1262::ADS1262() {
    _csPin = DEFAULT_CS_PIN;
    _drdyPin = DEFAULT_DRDY_PIN;
    _startPin = DEFAULT_START_PIN;
    _pwdnPin = DEFAULT_PWDN_PIN;
    _spi = &SPI;
    _initialized = false;
    _continuousMode = false;
    _vref = 2.5f; // Default internal reference voltage
    
    // Set default configuration
    _config.dataRate = ADS1262_DR_100_SPS;
    _config.gain = ADS1262_GAIN_1;
    _config.reference = ADS1262_REF_INTERNAL_2_5V;
    _config.continuousMode = false;
    _config.bufferEnabled = false;
    _config.filterType = 0;
}

// Constructor with custom pin assignments and default SPI
ADS1262::ADS1262(uint8_t csPin, uint8_t drdyPin, uint8_t startPin, uint8_t pwdnPin) {
    _csPin = csPin;
    _drdyPin = drdyPin;
    _startPin = startPin;
    _pwdnPin = pwdnPin;
    _spi = &SPI;
    _initialized = false;
    _continuousMode = false;
    _vref = 2.5f; // Default internal reference voltage
    
    // Set default configuration
    _config.dataRate = ADS1262_DR_100_SPS;
    _config.gain = ADS1262_GAIN_1;
    _config.reference = ADS1262_REF_INTERNAL_2_5V;
    _config.continuousMode = false;
    _config.bufferEnabled = false;
    _config.filterType = 0;
}

// Constructor with custom pin assignments and SPI instance
ADS1262::ADS1262(uint8_t csPin, uint8_t drdyPin, uint8_t startPin, uint8_t pwdnPin, SPIClass* spi) {
    _csPin = csPin;
    _drdyPin = drdyPin;
    _startPin = startPin;
    _pwdnPin = pwdnPin;
    _spi = spi ? spi : &SPI; // Use provided SPI or default
    _initialized = false;
    _continuousMode = false;
    _vref = 2.5f; // Default internal reference voltage
    
    // Set default configuration
    _config.dataRate = ADS1262_DR_100_SPS;
    _config.gain = ADS1262_GAIN_1;
    _config.reference = ADS1262_REF_INTERNAL_2_5V;
    _config.continuousMode = false;
    _config.bufferEnabled = false;
    _config.filterType = 0;
}

// Initialize the ADS1262 with default configuration
bool ADS1262::begin(bool startSPI) {
    return begin(_config, startSPI);
}

// Initialize the ADS1262 with custom configuration
bool ADS1262::begin(const ADS1262_Config& config, bool startSPI) {
    _config = config;
    
    setupPins();
    setupSPI(startSPI);
    
    // Power up and reset the device
    powerUp();
    delay(100);
    resetDevice();
    delay(100);
    
    // Check device connection
    if (!testConnection()) {
        return false;
    }
    
    // Apply configuration
    applyConfiguration();
    
    _initialized = true;
    return true;
}

// Initialize the ADS1262 with custom SPI pins (ESP32 style)
bool ADS1262::begin(uint8_t sck, uint8_t miso, uint8_t mosi) {
    return begin(sck, miso, mosi, _config);
}

// Initialize the ADS1262 with custom SPI pins and configuration
bool ADS1262::begin(uint8_t sck, uint8_t miso, uint8_t mosi, const ADS1262_Config& config) {
    _config = config;
    
    setupPins();
    setupSPI(sck, miso, mosi);
    
    // Power up and reset the device
    powerUp();
    delay(100);
    resetDevice();
    delay(100);
    
    // Check device connection
    if (!testConnection()) {
        return false;
    }
    
    // Apply configuration
    applyConfiguration();
    
    _initialized = true;
    return true;
}

// Cleanup and disable the ADS1262
void ADS1262::end() {
    if (_initialized) {
        stopConversion();
        powerDown();
        _initialized = false;
    }
}

// Setup pin modes and initial states
void ADS1262::setupPins() {
    pinMode(_csPin, OUTPUT);
    pinMode(_drdyPin, INPUT);
    pinMode(_startPin, OUTPUT);
    pinMode(_pwdnPin, OUTPUT);
    
    digitalWrite(_csPin, HIGH);
    digitalWrite(_startPin, LOW);
    digitalWrite(_pwdnPin, HIGH);
}

// Setup SPI communication
// Setup SPI interface
void ADS1262::setupSPI(bool startSPI) {
    if (startSPI && _spi) {
        _spi->begin();
    }
}

// Setup SPI interface with custom pins (ESP32 style)
void ADS1262::setupSPI(uint8_t sck, uint8_t miso, uint8_t mosi) {
    if (_spi) {
        // Some cores implement SPI.begin(SCK, MISO, MOSI). Only call that overload
        // on platforms that provide it (ESP32). Otherwise fall back to _spi->begin().
#if defined(ARDUINO_ARCH_ESP32)
        _spi->begin(sck, miso, mosi);
#else
        _spi->begin();
#endif
    }
}

// Reset the device using the RESET command
void ADS1262::resetDevice() {
    spiCommand(ADS1262_CMD_RESET);
    delay(100);
}
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

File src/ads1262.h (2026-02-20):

/*
 * Arduino library for the ADS1262 32-bit ADC breakout board from ProtoCentral
 * 
 * SPDX-License-Identifier: MIT
 * 
 * Author: Ashwin Whitchurch, Protocentral Electronics
 * Contact: support@protocentral.com
 * Copyright (c) 2020-2025 ProtoCentral Electronics
 *
 * This software is licensed under the MIT License
 * 
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
 * For information on how to use, visit:
 * https://github.com/Protocentral/protocentral-ads1262-arduino
 */

#ifndef ADS1262_H
#define ADS1262_H

#include <Arduino.h>
#include <SPI.h>

// Library version
#define ADS1262_LIBRARY_VERSION "2.0.1"

// SPI Configuration
#define ADS1262_SPI_DUMMY_BYTE    0xFF
#define ADS1262_SPI_CLOCK_SPEED   1000000  // 1MHz

// ADS1262 Commands
#define ADS1262_CMD_NOP           0x00    // No operation
#define ADS1262_CMD_RESET         0x06    // Reset device
#define ADS1262_CMD_START         0x08    // Start/restart conversions
#define ADS1262_CMD_STOP          0x0A    // Stop conversion
#define ADS1262_CMD_RDATA         0x12    // Read data by command
#define ADS1262_CMD_RDATAC        0x10    // Enable read data continuous mode
#define ADS1262_CMD_SDATAC        0x11    // Stop read data continuous mode
#define ADS1262_CMD_RREG          0x20    // Read register (ORed with register address)
#define ADS1262_CMD_WREG          0x40    // Write register (ORed with register address)

// ADS1262 Register Addresses
#define ADS1262_REG_ID            0x00    // Device ID
#define ADS1262_REG_POWER         0x01    // Power control
#define ADS1262_REG_INTERFACE     0x02    // Interface control
#define ADS1262_REG_MODE0         0x03    // Mode control 0
#define ADS1262_REG_MODE1         0x04    // Mode control 1
#define ADS1262_REG_MODE2         0x05    // Mode control 2
#define ADS1262_REG_INPMUX        0x06    // Input multiplexer
#define ADS1262_REG_OFCAL0        0x07    // Offset calibration 0
#define ADS1262_REG_OFCAL1        0x08    // Offset calibration 1
#define ADS1262_REG_OFCAL2        0x09    // Offset calibration 2
#define ADS1262_REG_FSCAL0        0x0A    // Full-scale calibration 0
#define ADS1262_REG_FSCAL1        0x0B    // Full-scale calibration 1
#define ADS1262_REG_FSCAL2        0x0C    // Full-scale calibration 2
#define ADS1262_REG_IDACMUX       0x0D    // IDAC multiplexer
#define ADS1262_REG_IDACMAG       0x0E    // IDAC magnitude
#define ADS1262_REG_REFMUX        0x0F    // Reference multiplexer
#define ADS1262_REG_TDACP         0x10    // Test DAC positive
#define ADS1262_REG_TDACN         0x11    // Test DAC negative
#define ADS1262_REG_GPIOCON       0x12    // GPIO connection
#define ADS1262_REG_GPIODIR       0x13    // GPIO direction
#define ADS1262_REG_GPIODAT       0x14    // GPIO data
#define ADS1262_REG_ADC2CFG       0x15    // ADC2 configuration
#define ADS1262_REG_ADC2MUX       0x16    // ADC2 multiplexer
#define ADS1262_REG_ADC2OFC0      0x17    // ADC2 offset calibration 0
#define ADS1262_REG_ADC2OFC1      0x18    // ADC2 offset calibration 1
#define ADS1262_REG_ADC2FSC0      0x19    // ADC2 full-scale calibration 0
#define ADS1262_REG_ADC2FSC1      0x1A    // ADC2 full-scale calibration 1

// Default pin assignments (can be overridden in constructor)
static constexpr uint8_t DEFAULT_CS_PIN = 7;     ///< Default chip select pin
static constexpr uint8_t DEFAULT_DRDY_PIN = 6;   ///< Default data ready pin  
static constexpr uint8_t DEFAULT_START_PIN = 5;  ///< Default start pin
static constexpr uint8_t DEFAULT_PWDN_PIN = 4;   ///< Default power down pin

// Data rates (POWER register values)
enum ADS1262_DataRate {
    ADS1262_DR_2_5_SPS    = 0x00,
    ADS1262_DR_5_SPS      = 0x01,
    ADS1262_DR_10_SPS     = 0x02,
    ADS1262_DR_16_6_SPS   = 0x03,
    ADS1262_DR_20_SPS     = 0x04,
    ADS1262_DR_50_SPS     = 0x05,
    ADS1262_DR_60_SPS     = 0x06,
    ADS1262_DR_100_SPS    = 0x07,
    ADS1262_DR_400_SPS    = 0x08,
    ADS1262_DR_1200_SPS   = 0x09,
    ADS1262_DR_2400_SPS   = 0x0A,
    ADS1262_DR_4800_SPS   = 0x0B,
    ADS1262_DR_7200_SPS   = 0x0C,
    ADS1262_DR_14400_SPS  = 0x0D,
    ADS1262_DR_19200_SPS  = 0x0E,
    ADS1262_DR_38400_SPS  = 0x0F
};

// Gain settings (MODE2 register values)
enum ADS1262_Gain {
    ADS1262_GAIN_1   = 0x00,
    ADS1262_GAIN_2   = 0x01,
    ADS1262_GAIN_4   = 0x02,
    ADS1262_GAIN_8   = 0x03,
    ADS1262_GAIN_16  = 0x04,
    ADS1262_GAIN_32  = 0x05
};

// Input channel selections
enum ADS1262_InputChannel {
    ADS1262_AIN0  = 0x00,
    ADS1262_AIN1  = 0x01,
    ADS1262_AIN2  = 0x02,
    ADS1262_AIN3  = 0x03,
    ADS1262_AIN4  = 0x04,
    ADS1262_AIN5  = 0x05,
    ADS1262_AIN6  = 0x06,
    ADS1262_AIN7  = 0x07,
    ADS1262_AIN8  = 0x08,
    ADS1262_AIN9  = 0x09,
    ADS1262_AINCOM = 0x0A,
    ADS1262_TEMP_SENSOR_P = 0x0B,
    ADS1262_TEMP_SENSOR_N = 0x0C,
    ADS1262_AVDD_MONITOR = 0x0D,
    ADS1262_DVDD_MONITOR = 0x0E,
    ADS1262_TDAC_TEST = 0x0F
};

// Reference selections
enum ADS1262_Reference {
    ADS1262_REF_INTERNAL_2_5V = 0x00,
    ADS1262_REF_EXTERNAL_AIN0_AIN1 = 0x01,
    ADS1262_REF_EXTERNAL_AIN2_AIN3 = 0x02,
    ADS1262_REF_INTERNAL_AVDD_AVSS = 0x03
};

/**
 * @brief Configuration structure for ADS1262 settings
 */
struct ADS1262_Config {
    ADS1262_DataRate dataRate;     ///< ADC sampling rate
    ADS1262_Gain gain;             ///< Programmable gain amplifier setting
    ADS1262_Reference reference;   ///< Reference voltage source
    bool continuousMode;           ///< Enable continuous conversion mode
    bool bufferEnabled;            ///< Enable input buffer
    uint8_t filterType;            ///< Digital filter type
};

/**
 * @brief Arduino library for the ADS1262 32-bit delta-sigma ADC
 * 
 * This class provides a comprehensive interface to the Texas Instruments ADS1262
 * 32-bit precision ADC. Features include:
 * - Easy configuration and initialization
 * - Both blocking and non-blocking data acquisition
 * - Automatic voltage conversion with programmable gain
 * - Support for multiple reference sources
 * - Calibration functions
 * - Error handling and device verification
 * 
 * @note This library requires the SPI library
 * 
 * @author ProtoCentral Electronics
 * @version 2.0.1
 */

class ADS1262 {
private:
    // Pin assignments
    uint8_t _csPin;
    uint8_t _drdyPin;
    uint8_t _startPin;
    uint8_t _pwdnPin;
    
    // SPI interface
    SPIClass* _spi;
    
    // Configuration
    ADS1262_Config _config;
    bool _initialized;
    bool _continuousMode;
    
    // Internal reference voltage (for calculations)
    float _vref;
    
    // Private methods
    void spiCommand(uint8_t command);
    void spiWriteReg(uint8_t reg, uint8_t value);
    uint8_t spiReadReg(uint8_t reg);
    void waitForDRDY(uint32_t timeout_ms = 1000);
    void setupSPI(bool startSPI = true);
    void setupSPI(uint8_t sck, uint8_t miso, uint8_t mosi);
    void setupPins();
    void resetDevice();
    void applyConfiguration();
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

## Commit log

2016-07-07 arduino basic analog read-out sketch
2016-07-07 Arduino libraries
2026-02-20 Fix LED BUILTIN issue
    [04-Advanced-Usage.ino]
2026-10-06 Add v4 breakout hardware (KiCad + schematic PDF)
    v4 runs from a single 3.3 V / 5 V supply pin: an LM2775 charge pump
    makes the 5 V analog rail, with a two-stage LC filter. Original Eagle
    files stay in /Hardware.
    [brk_ads1262_v4.kicad_pcb, brk_ads1262_v4.kicad_sch]

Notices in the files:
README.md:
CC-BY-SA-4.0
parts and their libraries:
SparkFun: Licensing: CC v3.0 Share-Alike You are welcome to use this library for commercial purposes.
